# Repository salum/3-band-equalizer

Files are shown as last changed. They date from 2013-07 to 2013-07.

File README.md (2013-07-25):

# Equalizador de 3 bandas

Os Equalisadores de onda, consistem em controlar as frequências de um determinado sinal a fim de modificar a amplitude de uma certa frequência.

No caso de equalisadores de audio mais convencionais, utilizamos uma divisão simplificada das freqências, sendo elas denominadas baixas, médias e altas frequências, que regulam o grave (bass), medio(middle) e agudo(treble) respectivamente.

Para fim deste projeto, podemos considerar a seguinte sequência de blocos:

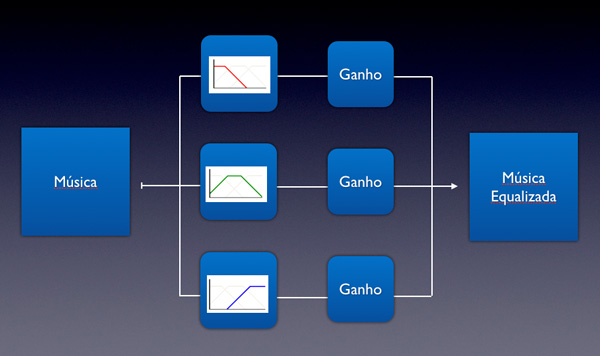
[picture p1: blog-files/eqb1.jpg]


Agora a pergunta seria: Qual tipo de filtro devemos utilizar?

Para responder esta pergunta, vamos olhar a tabela de filtros a segui, olhando qual filtro possui a característica que queremos, que é um filtro que possua uma linearidade maior em uma certa faixa de frequências.

Ao observarmos, o filtro que melhor se adapta é o Butterworth, que possui uma qualidade 0.707 e proporciona uma amplitude homogênia.

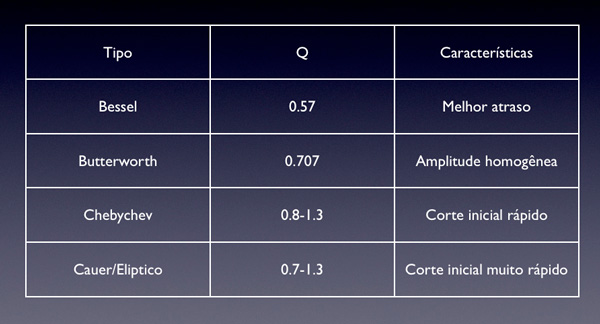
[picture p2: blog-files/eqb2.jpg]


Agora que já sabemos qual o melhor tipo, precisamos avaliar qual deverá ser a ordem deste filtro pois será ela que determinará o quão precido o filtro será, ou seja, após a frequência de corte, ele diminuirá n*20 dB por década. Para isso iremos utilizar a Equação 1, onde n é a ordem do filtro.

A partir da equação e das informações supracitadas, chegamos em um filtro Butterworth de segunda ordem, que nos proporcionará um ganho uniforme no passa faixa, além de uma queda relativamente brusca (40 dB por década) nas frequências de corte.l



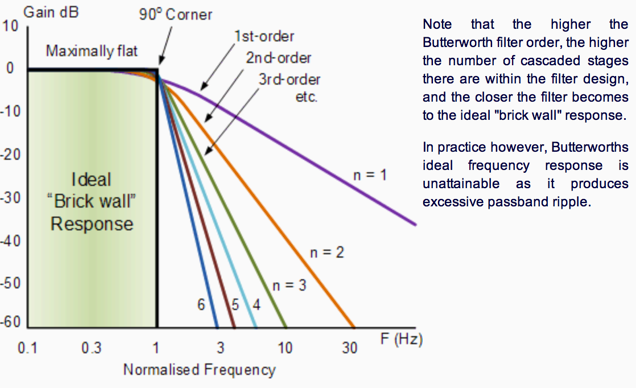
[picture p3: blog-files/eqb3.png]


Para determinarmos as frequências de corte, efetuamos pesquisas em livros, sites da internet e catálogos de equipamentos, onde verificamos que as frequências de corte são 300Hz e 3KHz.

A partir destes valores, e da equação padrão para determinação de frequências de corte, e fixando o valor da capacitância em 10uF, que proporciona uma constante de tempo baixa, chegamos nos valores de 53k e 5.3k para as frequências 300Hz e 3Khz respectivamente.

É importante notar que todo filtro Butterworth efetua uma defasagem de fase da ordem 90º, e que, no caso do Passabanda , que é formado por uma sequência de dois filtros, ocorre uma defasagem de 180º e que precisamos defasar este de -90º. Para isso adicionamos um "defasador" antes do passabanda.

A partir dos dados que possuímos, projetamos, simulamos, montamos e testamos os filtros necessários, utilizando a seguinte lista de componentes:

Protoboard
Ampop (TL074)
Capacitores de 10 uF
Resistores de 53K, 5.3K e 6.8K
Potenciômetros de 100K

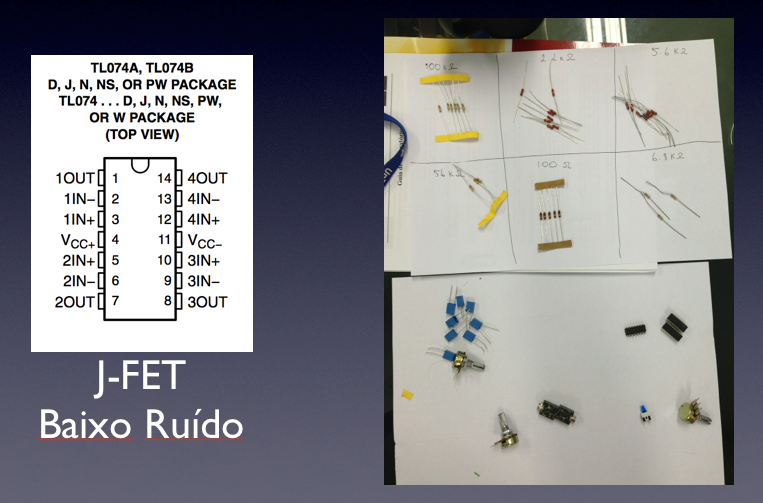
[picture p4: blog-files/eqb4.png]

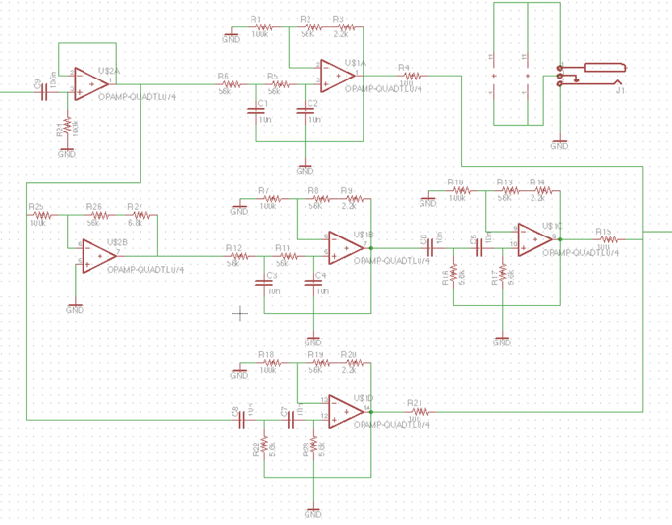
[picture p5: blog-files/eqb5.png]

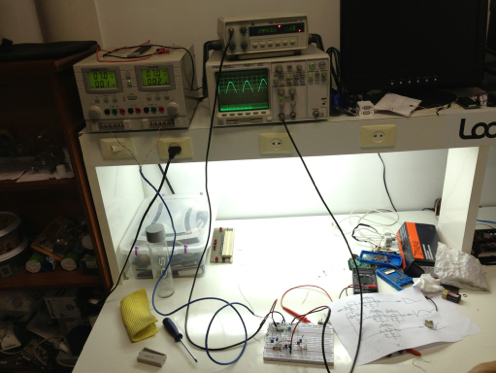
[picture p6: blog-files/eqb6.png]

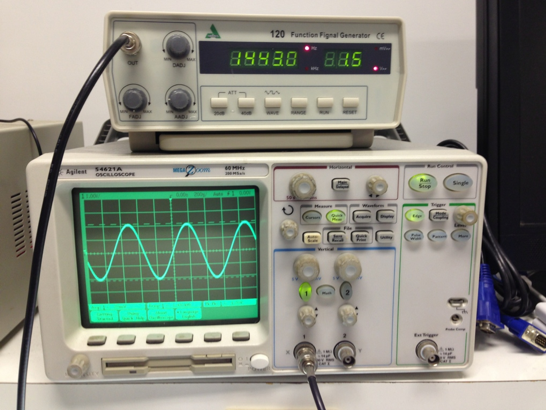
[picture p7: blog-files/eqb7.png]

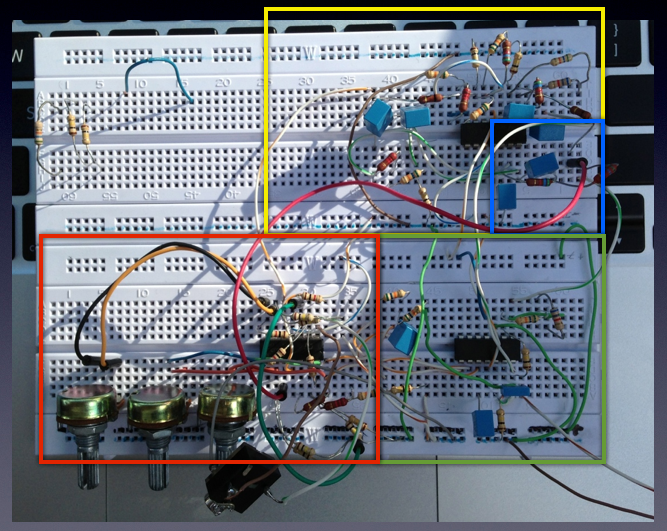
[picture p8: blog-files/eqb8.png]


Ao efetuarmos testes, notamos uma relação Sinal Ruido muito baixa, visto que estávamos efetuando uma amplificação no final de cada filtro.

Para uma segunda versão do atual projeto, iremos efetuar as seguintes tarefas.

- Avaliar técnicas de redução de ruídos
- Projetar divisor de tensão para utilizar somente uma fonte DC
- Estudar controle remoto do dispositivo
- Finalizar projeto PCB.

Bibliografia

- Integrated Electronics by Millman & Halkias

McGraw-Hill.

- Microelectronic Circuits 6th edition

[Download da apresentação 1](https://github.com/salum/3-band-equalizer/blob/master/presentations/1st%20presentation.pdf)

# Segunda versão
## implementação em PCB

Na segunda versão do Equalizador de 3 bandas, modificamos o projeto para obtermos uma redução de de ruídos, além de implementarmos ele em PCB, tornando o projeto mais robusto e mais organizado.

A fim de reduzirmos o ruído existente, decidimos por atuar no limite de saturação dos ampops, ou seja, adicionamos um amplificador de aproximadamente 8x na entrada do circuito.



Com esta modificação, foi necessário alterar também o modo com que os ampops de saída de cada faixa de equalização atuam, fazendo com que estes atuassem como atenuadores de sinal e não como amplificadores, como ocorrido na 1ª versão do projeto.

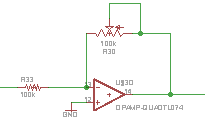
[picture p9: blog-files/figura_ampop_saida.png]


Após esta modificação do projeto, teremos o circuito a seguir, o qual deverá ser transferido para uma PCB.

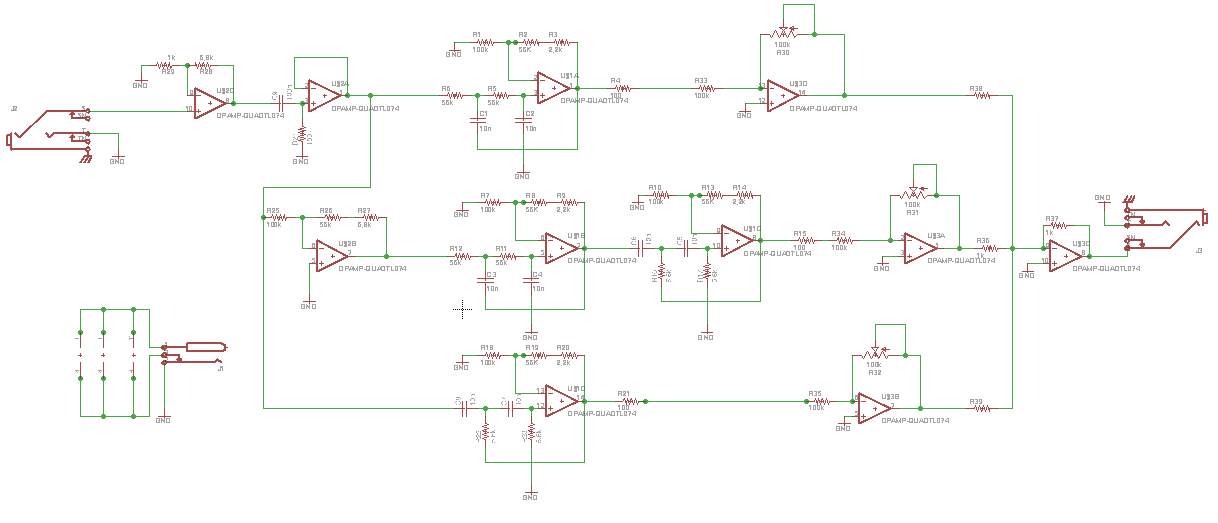
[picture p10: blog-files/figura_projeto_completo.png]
 

Para montarmos o projeto na PCB, utilizamos o software EAGLE - freeware e importando algumas bibliotecas externas do [Monowave](http://xdissent.github.io/monowave-eagle/libraries/index.html).

Após montarmos o circuito e posicionarmos as peças na placa, obtivemos o seguinte esquemático.

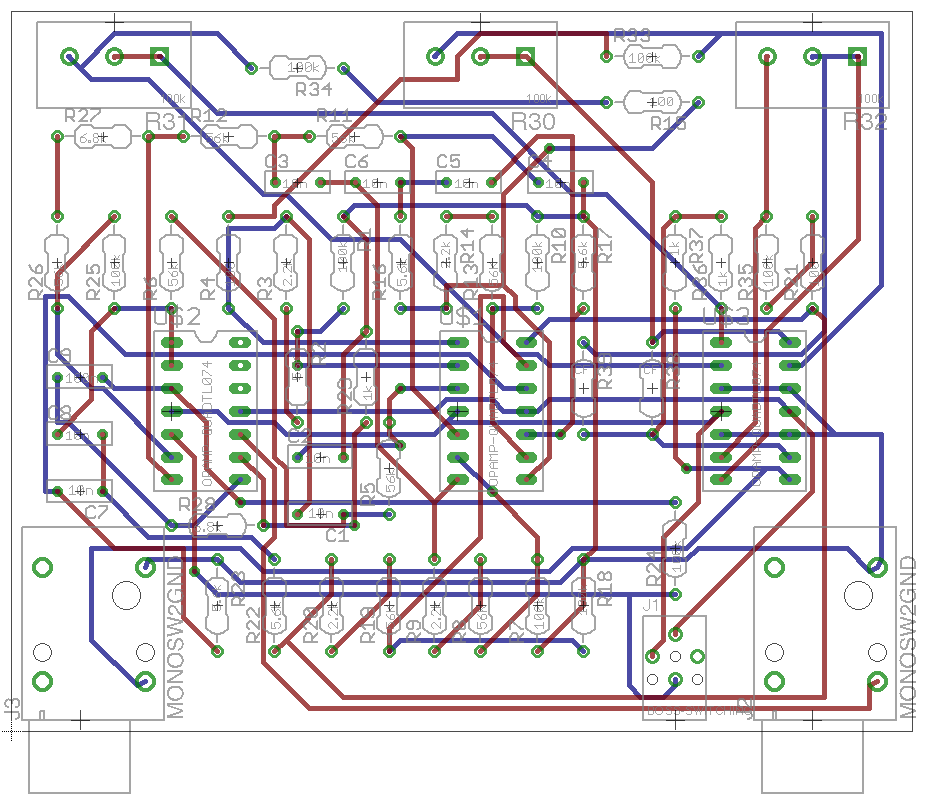
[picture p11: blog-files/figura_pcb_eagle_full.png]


Podemos notar que para fazermos tal placa, precisaríamos de impressão duplaface, além de trilhas de 10mm, o que dificulta a impressão e a montagem (sendo impossível fazer na DTL do SG11). Para isso, pegamos os padrões de impressão, assim como quais arquivos deveriam ser gerados para a confecção ser feita na Divisão Técnico Laboratorial do SG11 da Universidade de Brasília.

No final deste post tem um tutorial feito pelo Pedro Salum para auxiliar a impressão na DTL.

Ao observarmos o padrão necessário, tivemos que efetuar uma divisão do projeto da PCB em 3 partes, passa baixa, passa faixa e passa alta e depois interconectá-las por meio de fios.

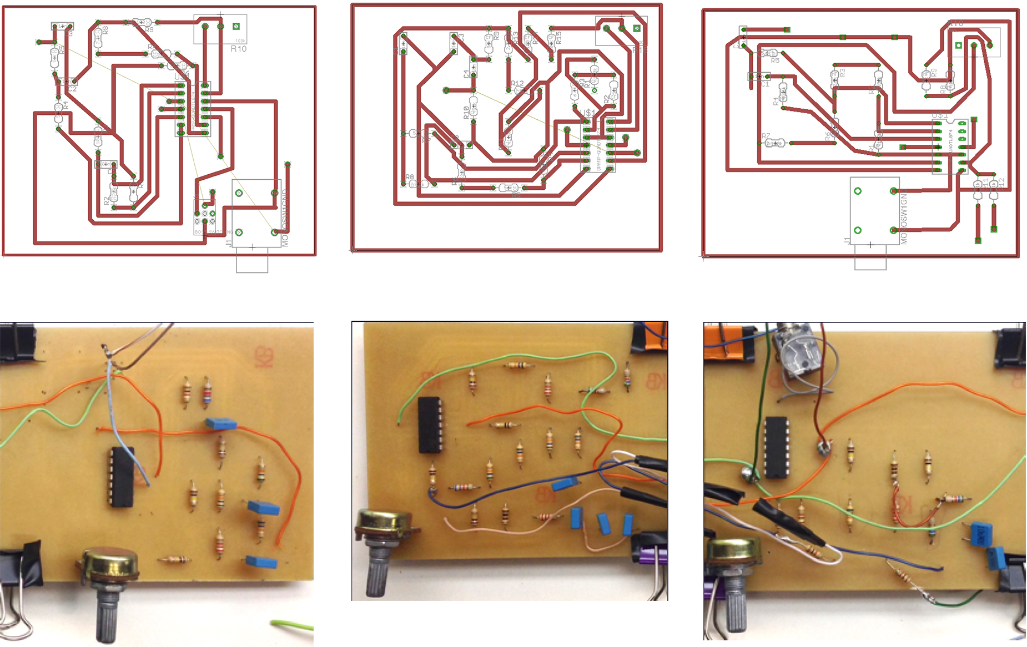
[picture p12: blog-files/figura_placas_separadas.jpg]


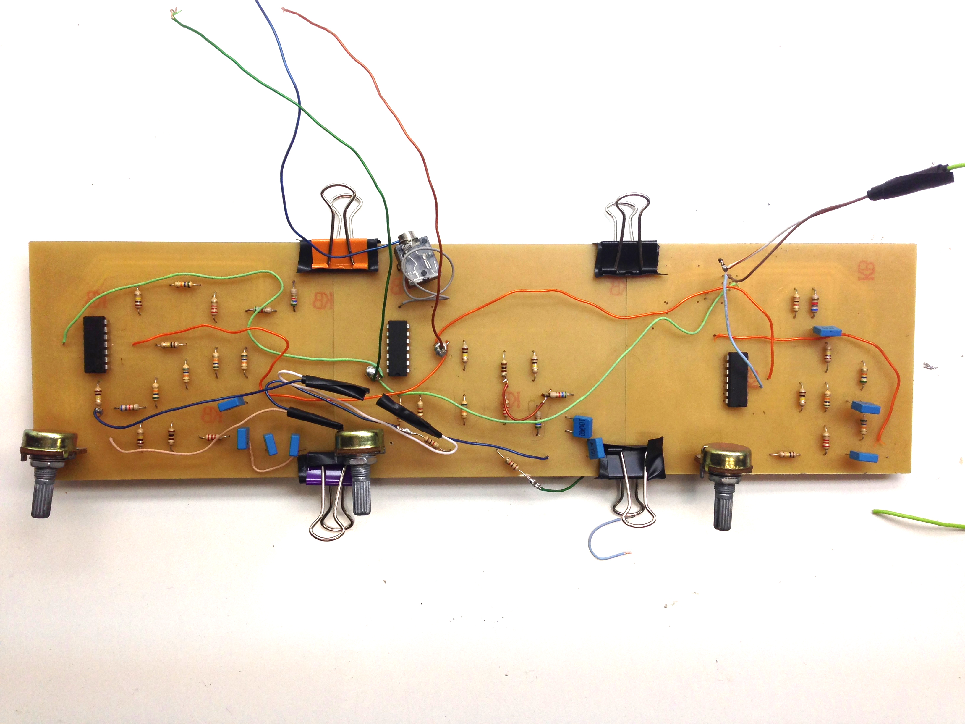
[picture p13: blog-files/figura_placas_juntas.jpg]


### Próximos passos

 - Empilhar placas a fim de reduzir espaço

 - criar uma case para o dispositivo

 - embutir um divisor de tensão a fim de utilizar uma fonte portátil.

[Download da Apresentação](https://github.com/salum/3-band-equalizer/raw/master/presentations/2nd%20presentation.pdf)

[Baixar Tutorial Eagle para Geber](#) (em breve)

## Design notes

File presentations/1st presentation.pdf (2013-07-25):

# Equalizador de 3 Bandas

3-band equalizer

# Equalizador de 3 Bandas

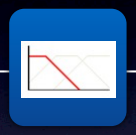
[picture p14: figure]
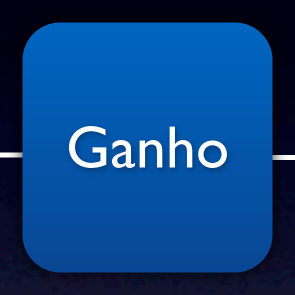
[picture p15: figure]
Ganho
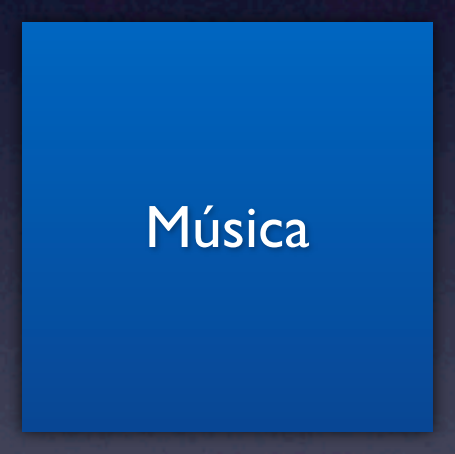
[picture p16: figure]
Música
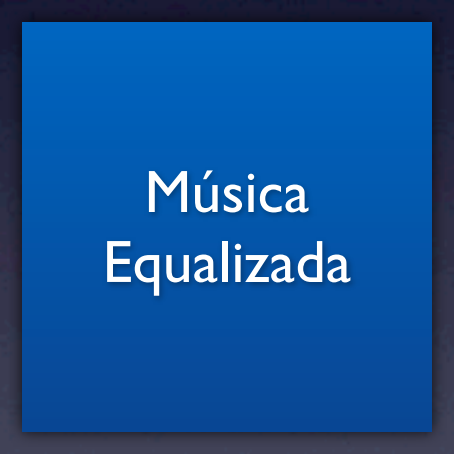
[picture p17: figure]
Música Equalizada
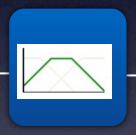
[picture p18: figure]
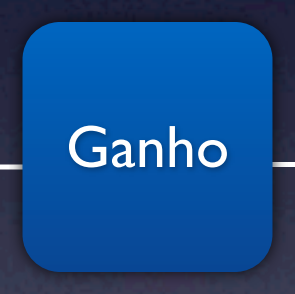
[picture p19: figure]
Ganho
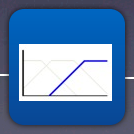
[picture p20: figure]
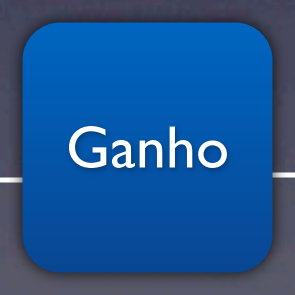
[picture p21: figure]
Ganho

# Equalizador de 3 Bandas

Tipo | Q | Características
Bessel | 0.57 | Melhor atraso
Butterworth | 0.707 | Amplitude homogênea
Chebychev | 0.8-1.3 | Corte inicial rápido
Cauer/Eliptico | 0.7-1.3 | Corte inicial muito rápido

# Equalizador de 3 Bandas

Filtros Butterworth

2ª Ordem

Q(fator de qualidade) = 0.707

Ganho uniforme em passa faixa

Queda brusca em frequências de corte

# Equalizador de 3 Bandas

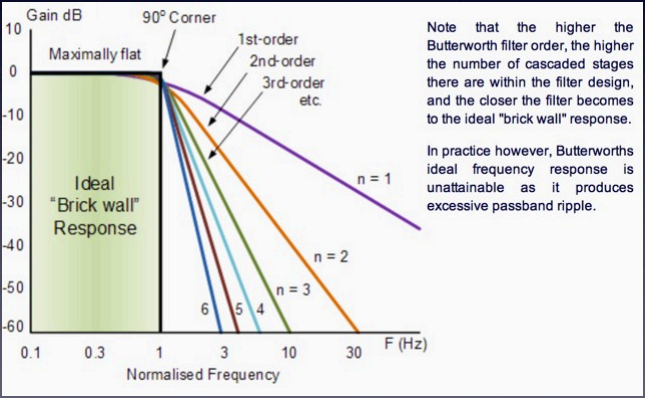
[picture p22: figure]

# Equalizador de 3 Bandas

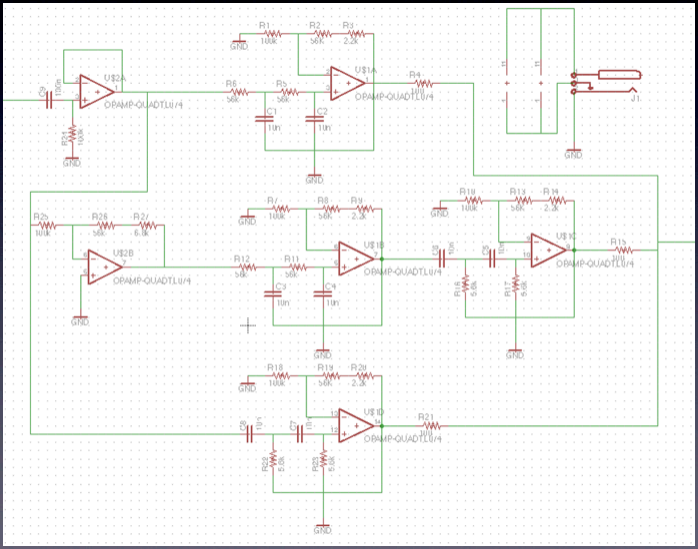
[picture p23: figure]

# Equalizador de 3 Bandas

f = 1 2.∏.R.C

C = 10nF
300Hz -- R = 53K
3KHz -- R = 5.3K

# Equalizador de 3 Bandas

Componentes Utilzados

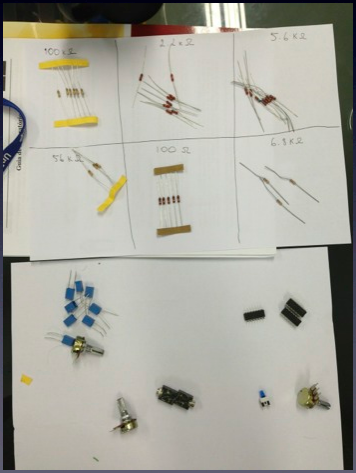
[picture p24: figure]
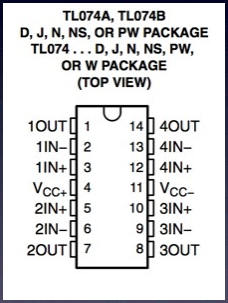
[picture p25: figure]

J-FET
Baixo Ruído

# Equalizador de 3 Bandas

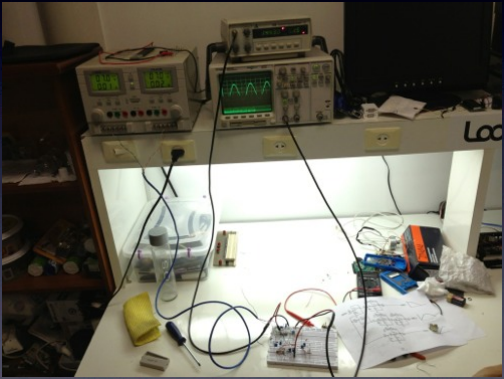
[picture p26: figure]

# Equalizador de 3 Bandas

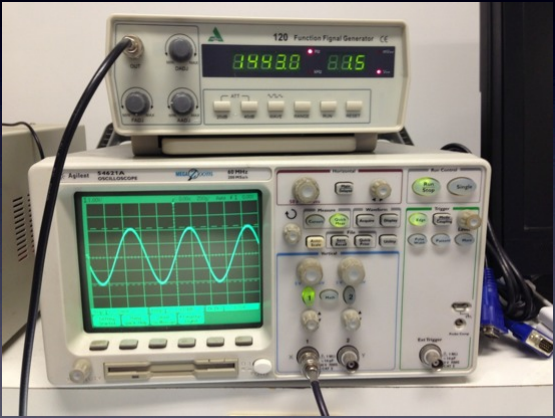
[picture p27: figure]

# Equalizador de 3 Bandas

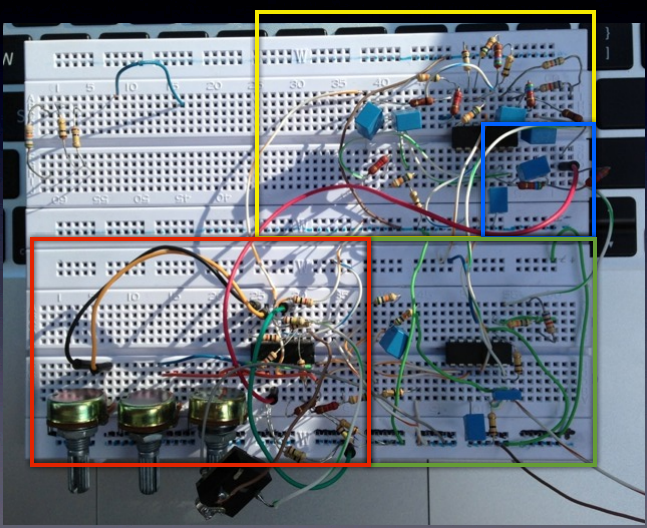
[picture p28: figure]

# Equalizador de 3 Bandas

Próximos Passos

- Avaliar técnicas de redução de ruídos;
- Projetar divisor de tensão para utilizar somente uma fonte DC;
- Estudar controle remoto do dispositivo;
- Finalizar projeto PCB.

# Equalizador de 3 Bandas

Bibliografia

- Integrated Electronics by Millman & Halkias McGraw-Hill.
- Microelectronic Circuits 6th edition

# Equalizador de 3 Bandas

Daniel Sandoval
Guilherme Alexsanders
Pedro Salum Franco

# Equalizador de 3 Bandas

## Dúvidas?

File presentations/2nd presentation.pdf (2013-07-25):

# Equalizador de 3 Bandas

3-band equalizer

# Equalizador de 3 Bandas

Ganho
Música
Música Equalizada
Ganho

# Equalizador de 3 Bandas

# Equalizador de 3 Bandas

Filtros Butterworth

# Equalizador de 3 Bandas

Filtros Butterworth

2ª Ordem

# Equalizador de 3 Bandas

Filtros Butterworth

2ª Ordem
Ganho uniforme em passa faixa

# Equalizador de 3 Bandas

Filtros Butterworth

2ª Ordem
Ganho uniforme em passa faixa

Queda brusca em frequências de corte

# Equalizador de 3 Bandas

f = 1 2.∏.R.C

C = 10nF
300Hz -- R = 53K
3KHz -- R = 5.3K

# Equalizador de 3 Bandas

Componentes Utilzados


J-FET
Baixo Ruído

# Equalizador de 3 Bandas

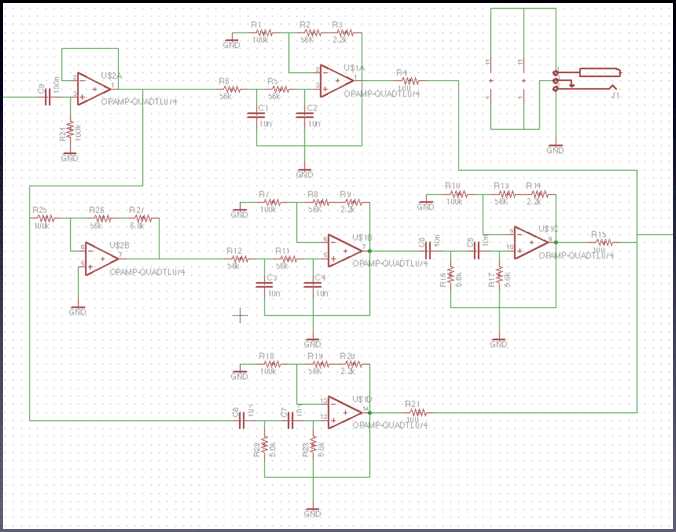
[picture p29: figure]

# Equalizador de 3 Bandas

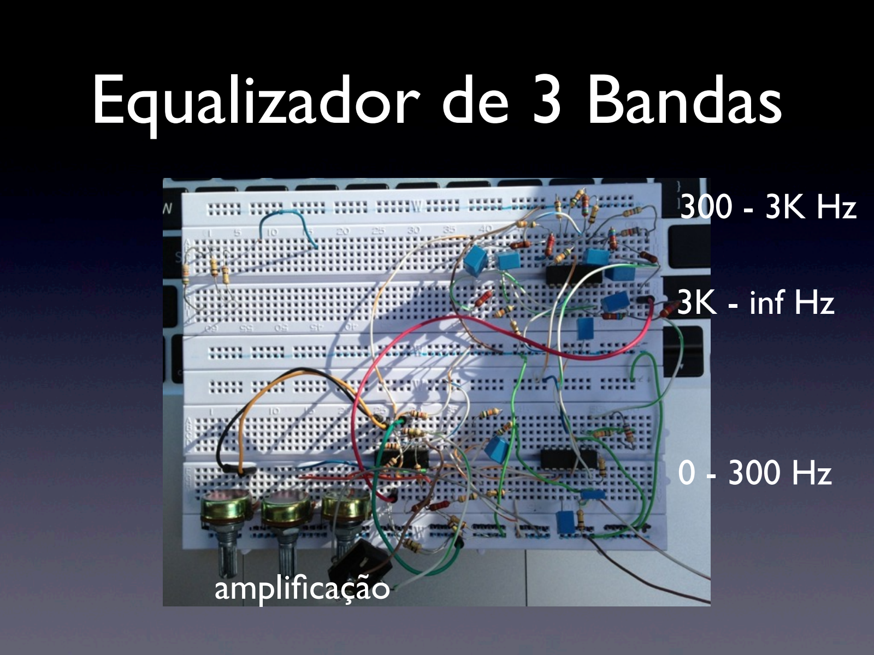
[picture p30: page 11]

amplificação

300 - 3K Hz

3K - inf Hz

0 - 300 Hz

# Equalizador de 3 Bandas

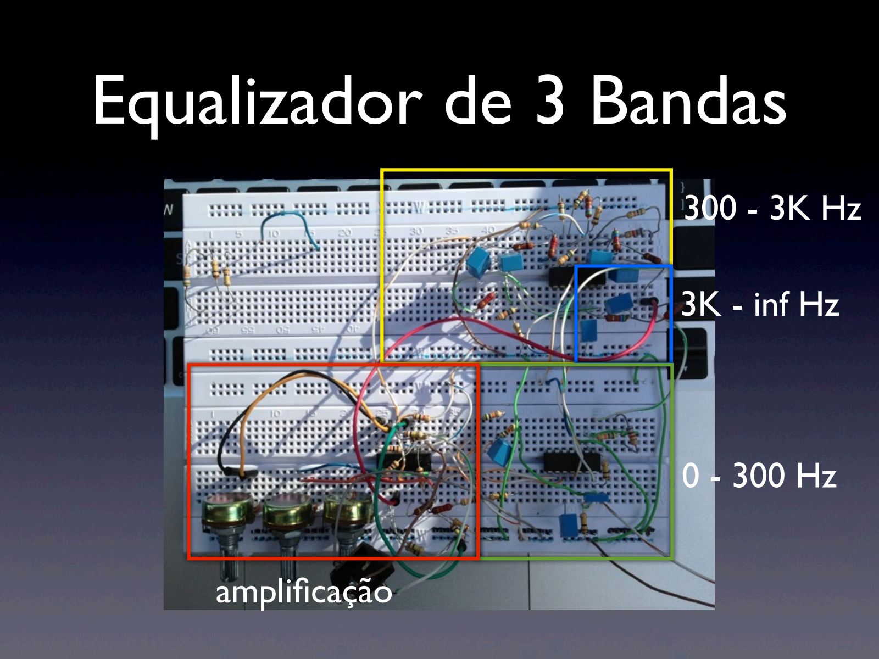
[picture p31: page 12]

amplificação

300 - 3K Hz

3K - inf Hz

0 - 300 Hz

# Equalizador de 3 Bandas

Problemas

- Ruido Aparente;
- Fisicamente Instável
- Necessita de fonte simétrica de 7V;

# Equalizador de 3 Bandas

# Equalizador de 3 Bandas

# Modelo 2.0

# Equalizador de 3 Bandas

Modelo 2.0

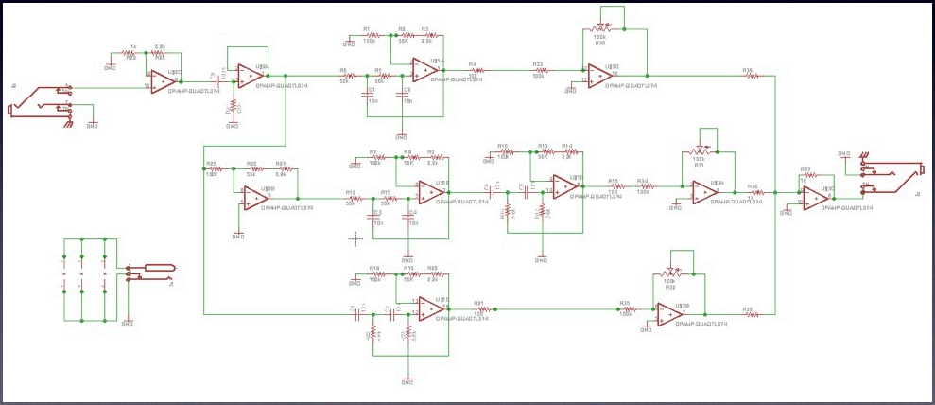
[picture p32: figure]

# Equalizador de 3 Bandas

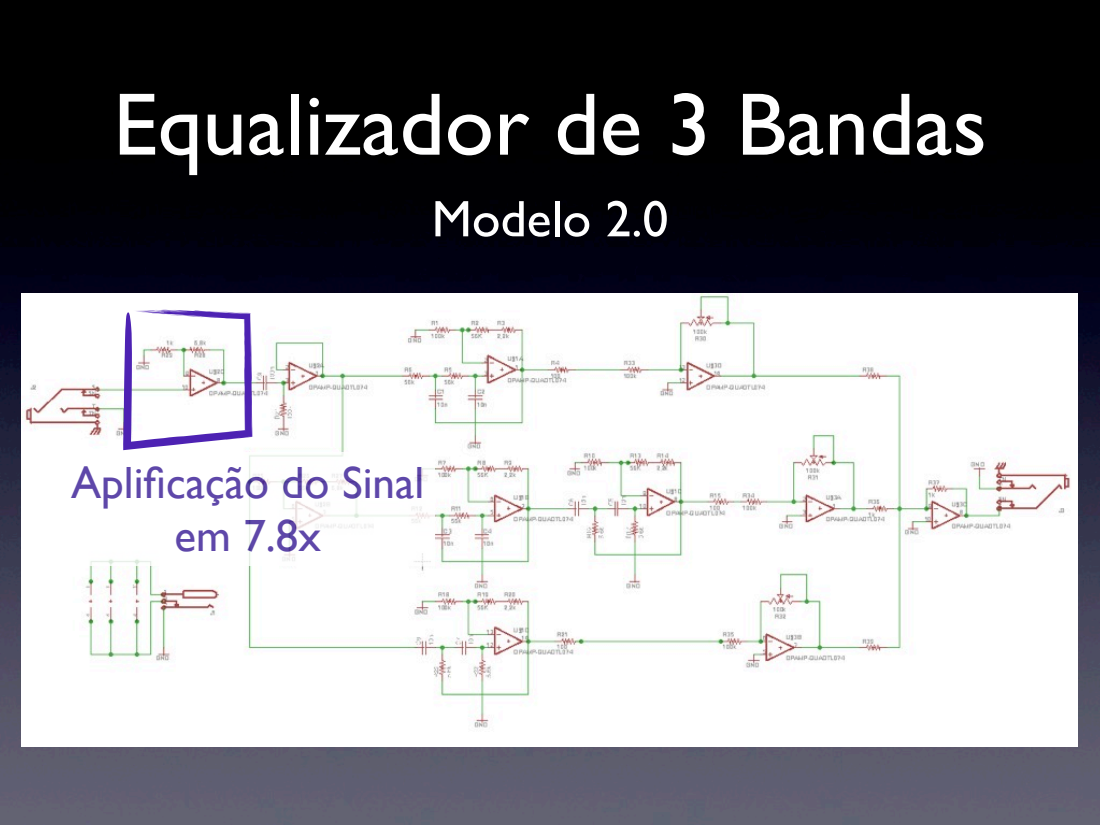
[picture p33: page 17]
Modelo 2.0

Aplificação do Sinal

# Equalizador de 3 Bandas

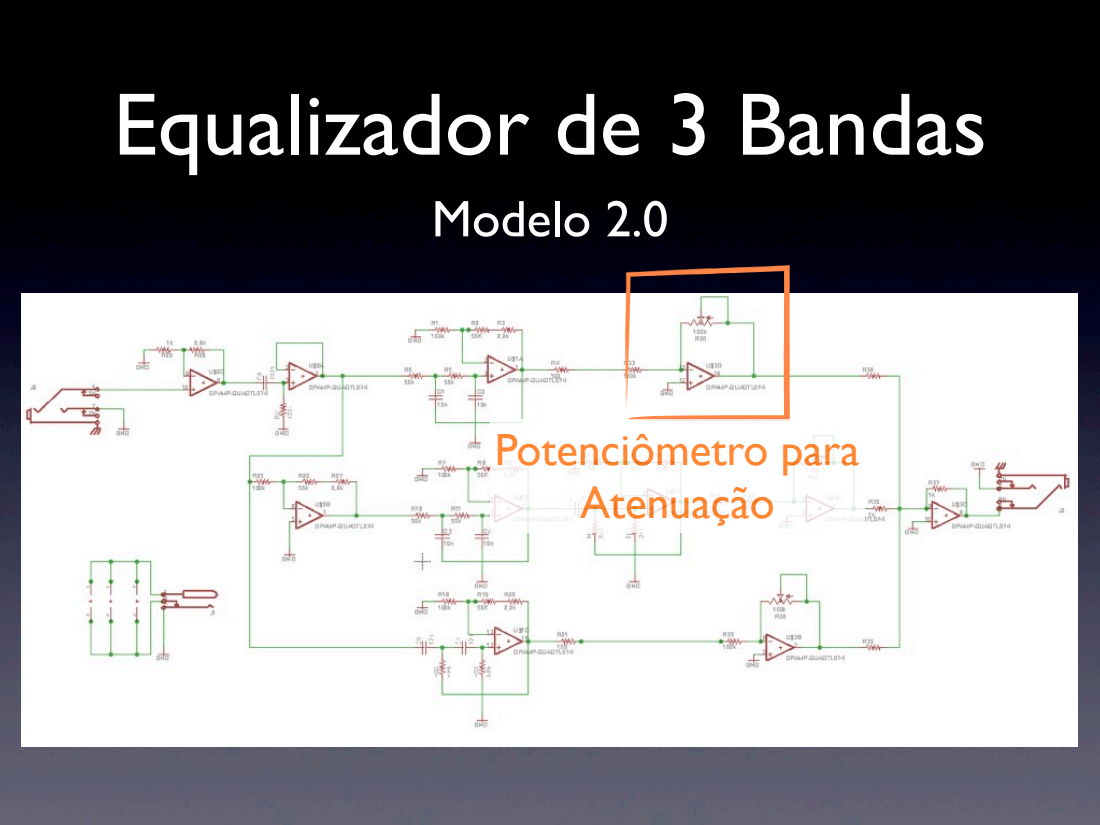
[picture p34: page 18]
Modelo 2.0; Potenciômetro para Atenuação

# Equalizador de 3 Bandas

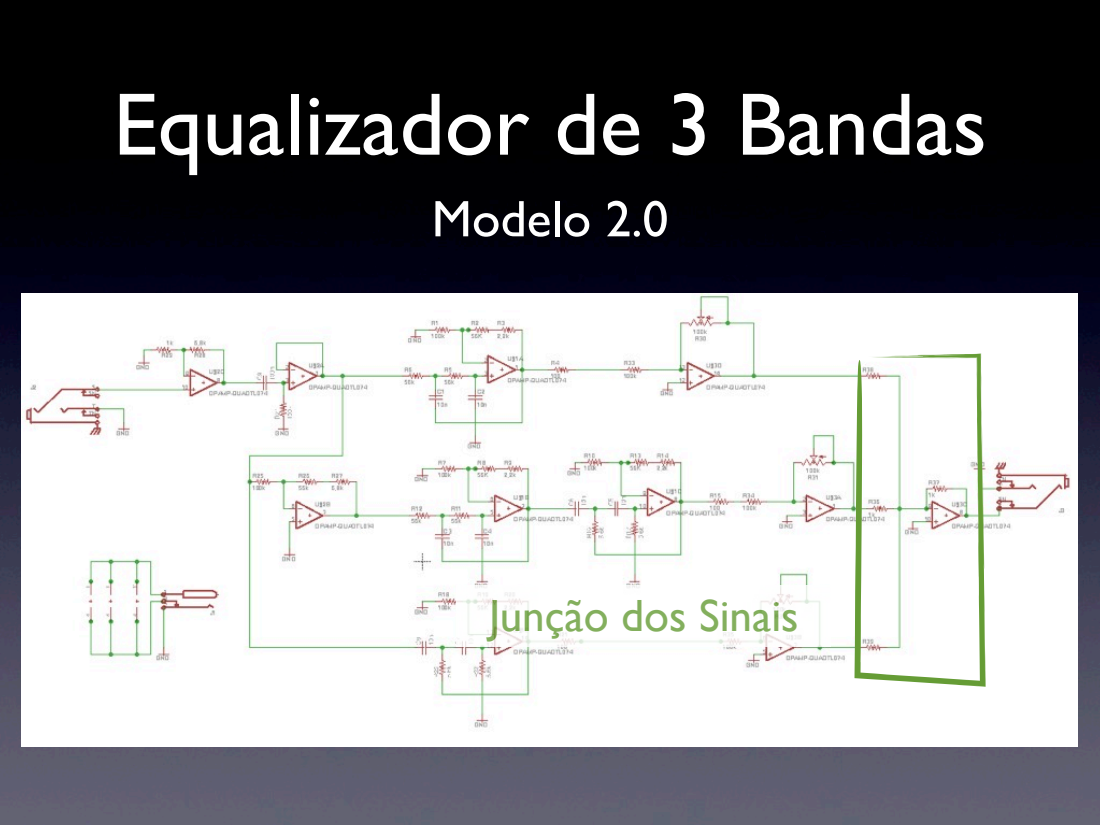
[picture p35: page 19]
Modelo 2.0

Junção dos Sinais

# Equalizador de 3 Bandas

Modelo 2.0

8 cm

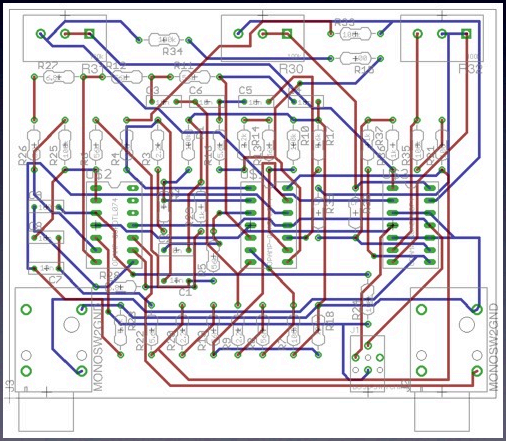
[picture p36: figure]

10 cm

# Equalizador de 3 Bandas

Modelo 2.0

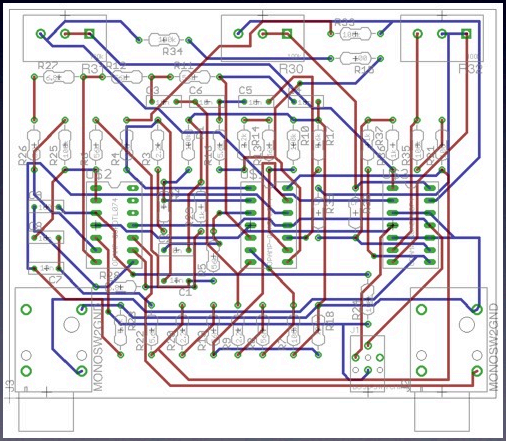
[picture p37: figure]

Trilhas pequenas

Dupla Face

Solda complicada

# Equalizador de 3 Bandas

Modelo 2.0

Dupla Face X Solda complicada

Trilhas pequenas

# Equalizador de 3 Bandas

Modelo 2.0


# Equalizador de 3 Bandas

Modelo 2.0

# Equalizador de 3 Bandas

Modelo 2.0


# Equalizador de 3 Bandas


Modelo 2.0

# Equalizador de 3 Bandas


Modelo 2.0

# Equalizador de 3 Bandas

Modelo 2.0


# Equalizador de 3 Bandas

Modelo 2.0
\m/

# Equalizador de 3 Bandas

Próximos Passos

- Empilhar as placas a fim de reduzir espaço
- Criar uma case para o dispositivo
- Embutir um divisor de tensão

# Equalizador de 3 Bandas

Bibliografia

- Integrated Electronics by Millman & Halkias McGraw-Hill.
- Microelectronic Circuits 6th edition

# Equalizador de 3 Bandas

Daniel Sandoval
Guilherme Aleksanders
Pedro Salum Franco

# Equalizador de 3 Bandas

## Dúvidas?

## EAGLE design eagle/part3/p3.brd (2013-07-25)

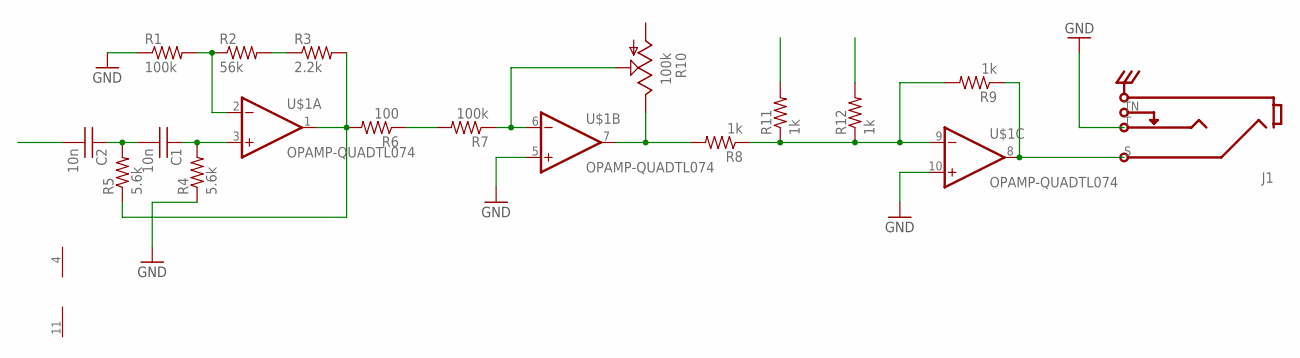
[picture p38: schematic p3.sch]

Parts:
C1, C2: 10n; BOX-2.5MM-7.2MM
J1: MONOSW1GND; NEUTRIK-NRJ4HM-1
R1, R7: 100k; 0.25W-0.4IN-METALFILM
R2: 56k; 0.25W-0.4IN-METALFILM
R3: 2.2k; 0.25W-0.4IN-METALFILM
R4, R5: 5.6k; 0.25W-0.4IN-METALFILM
R6: 100; 0.25W-0.4IN-METALFILM
R8, R9: 1k; 0.25W-0.4IN-METALFILM
R10: 100k; POT-SIDE-16MM-BITECH-P160KN
R11, R12: 1k; 0.25W-0.4IN
U$1: OPAMP-QUADTL074; DIP14

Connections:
0: J1.T, R1.1, R4.1, U$1.5 (IN+), U$1.10 (IN+)
unnamed: R1.2, R2.1, U$1.2 (IN-)
unnamed: R2.2, R3.1
unnamed: R3.2, R5.1, R6.2, U$1.1 (OUT)
unnamed: R6.1, R7.2
unnamed: R7.1, R10.P$2 (2), U$1.6 (IN-)
unnamed: R8.2, R10.P$3 (3), U$1.7 (OUT)
unnamed: R8.1, R9.2, R11.1, R12.1, U$1.9 (IN-)
unnamed: J1.S, R9.1, U$1.8 (OUT)
unnamed: C1.P$1 (1), R4.2, U$1.3 (IN+)
unnamed: C1.P$2 (2), C2.P$1 (1), R5.2
VCC: U$1.4 (VCC)
VEE: U$1.11 (VEE)

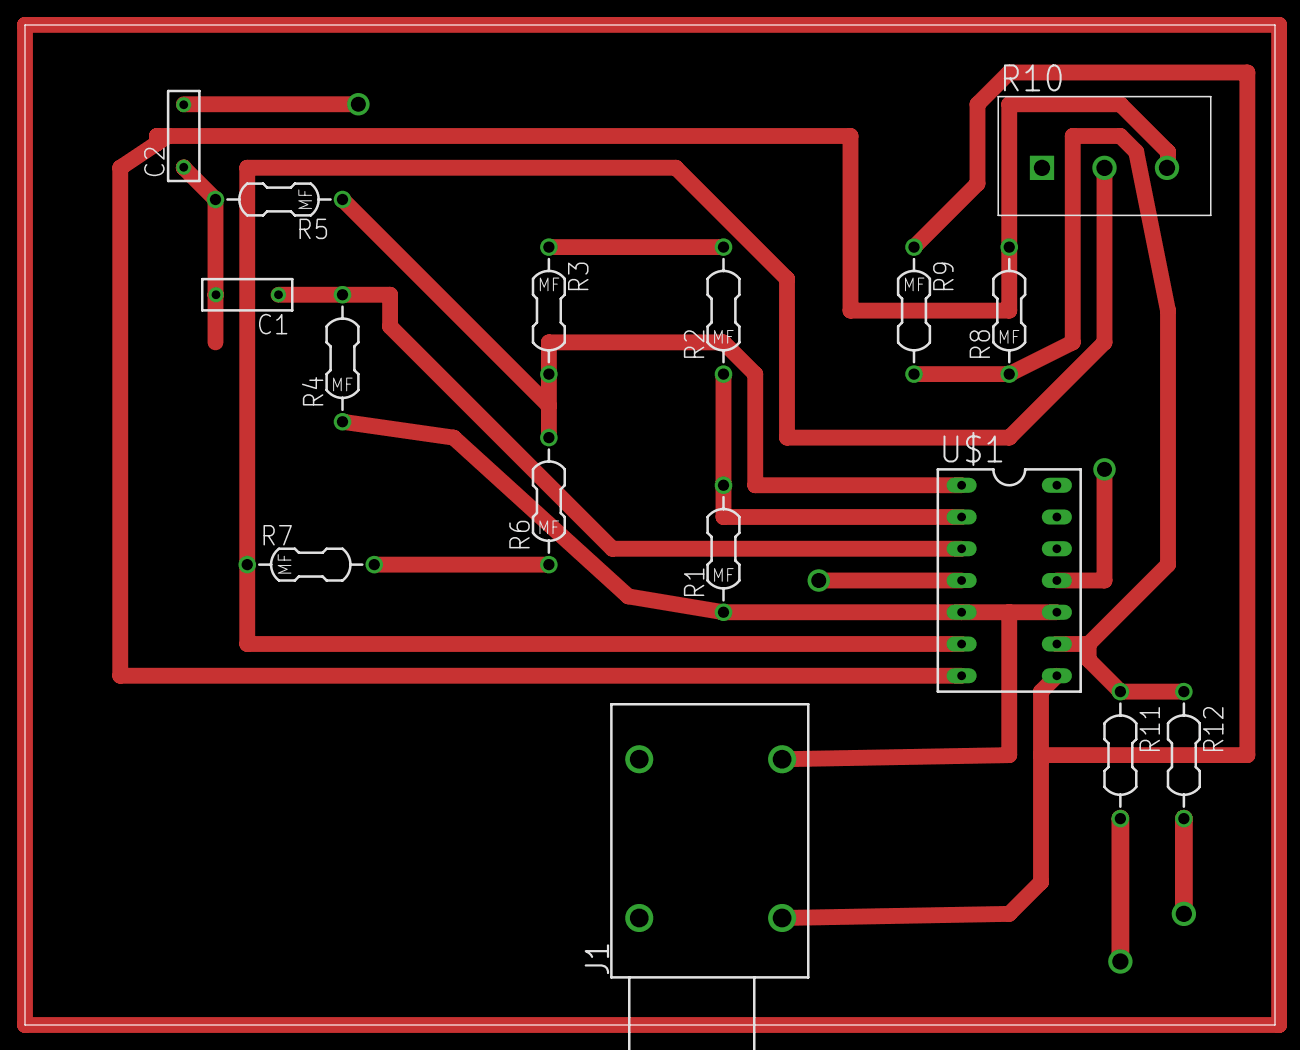
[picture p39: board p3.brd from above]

Board: 2 copper layers, 100.0 x 80.0 mm, 16 parts (0 on the bottom side), 11 nets.

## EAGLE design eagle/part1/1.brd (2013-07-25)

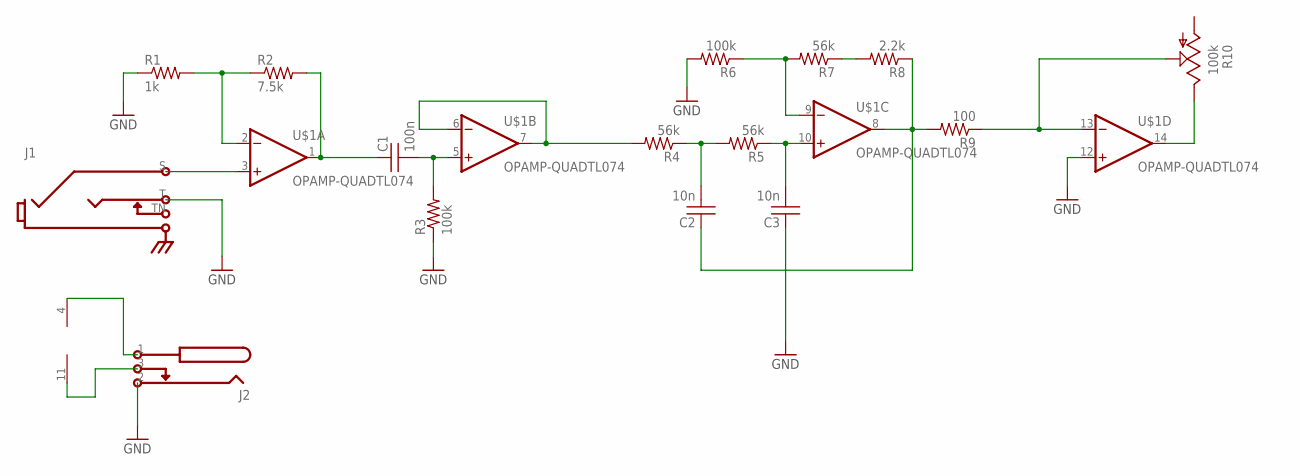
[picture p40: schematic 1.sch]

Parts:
C1: 100n; BOX-2.5MM-7.2MM
C2, C3: 10n; BOX-2.5MM-7.2MM
J1: MONOSW1GND; NEUTRIK-NRJ4HM-1
J2: BOSS-SWITCHING; KOBICONN-163-5010-E
R1: 1k; 0.25W-0.4IN-CARBONCOMP
R2: 7.5k; 0.25W-0.4IN-CARBONCOMP
R3, R6: 100k; 0.25W-0.4IN-CARBONCOMP
R4, R5, R7: 56k; 0.25W-0.4IN-CARBONCOMP
R8: 2.2k; 0.25W-0.4IN-CARBONCOMP
R9: 100; 0.25W-0.4IN-CARBONCOMP
R10: 100k; POT-SIDE-16MM-BITECH-P160KN
U$1: OPAMP-QUADTL074; DIP14

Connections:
0: C3.P$1 (1), J1.T, J2.2 (VCC), R1.1, R3.1, R6.2, U$1.12 (IN+)
unnamed: R1.2, R2.1, U$1.2 (IN-)
unnamed: C1.P$1 (1), R2.2, U$1.1 (OUT)
unnamed: C1.P$2 (2), R3.2, U$1.5 (IN+)
unnamed: R4.2, U$1.6 (IN-), U$1.7 (OUT)
unnamed: C2.P$2 (2), R4.1, R5.2
unnamed: C3.P$2 (2), R5.1, U$1.10 (IN+)
unnamed: R10.P$3 (3), U$1.14 (OUT)
unnamed: R6.1, R7.2, U$1.9 (IN-)
unnamed: R7.1, R8.2
unnamed: J1.S, U$1.3 (IN+)
unnamed: R9.1, R10.P$2 (2), U$1.13 (IN-)
unnamed: J2.1 (GND), U$1.4 (VCC)
unnamed: J2.3 (SW), U$1.11 (VEE)
unnamed: C2.P$1 (1), R8.1, R9.2, U$1.8 (OUT)

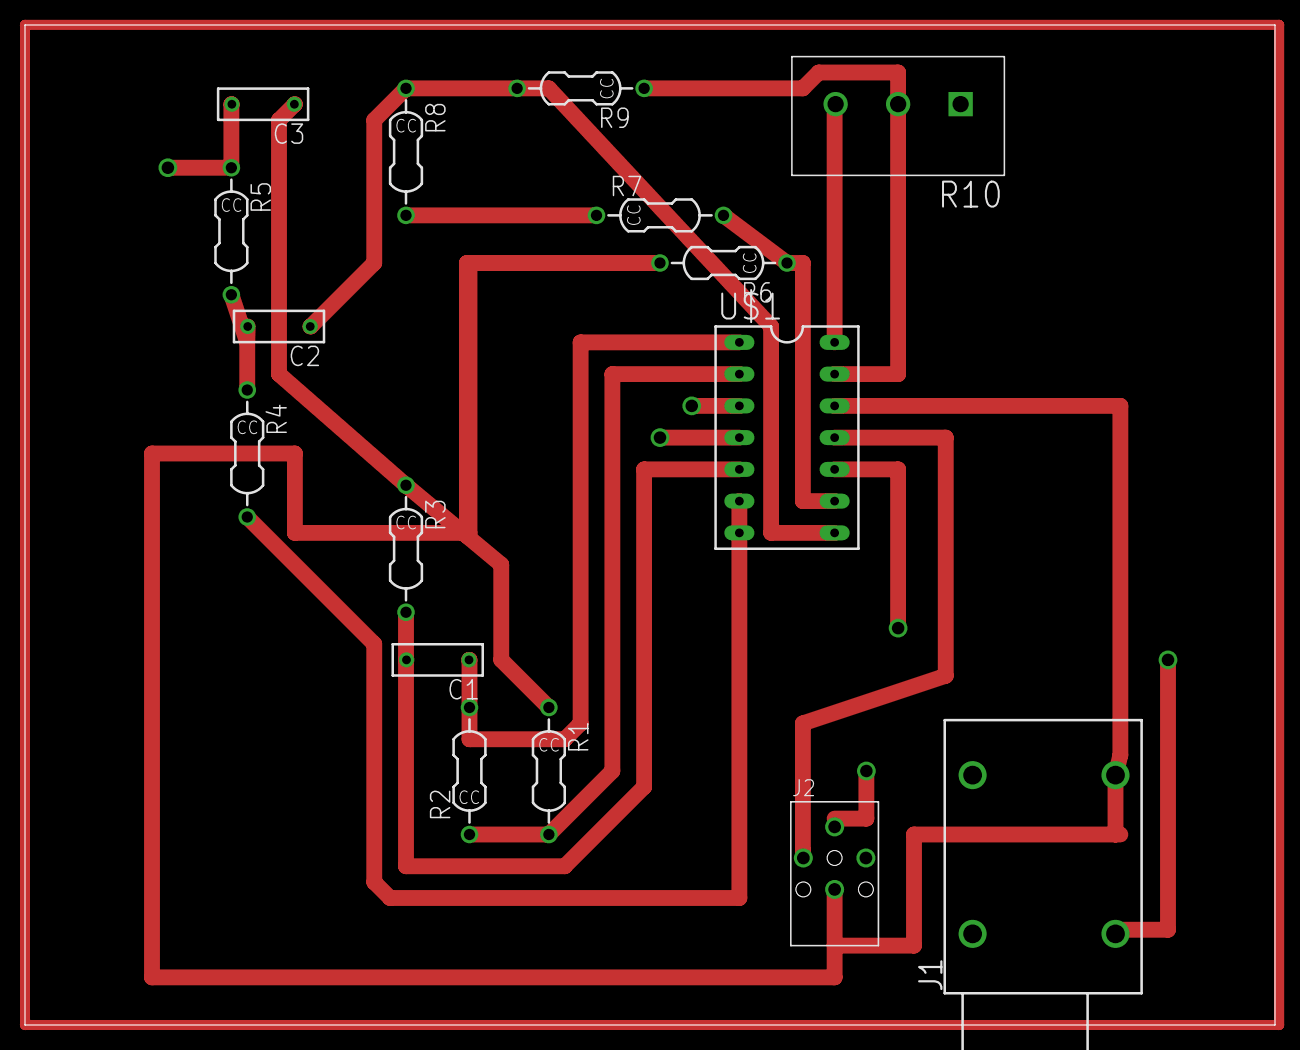
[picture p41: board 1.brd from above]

Board: 2 copper layers, 100.0 x 80.0 mm, 16 parts (0 on the bottom side), 15 nets.

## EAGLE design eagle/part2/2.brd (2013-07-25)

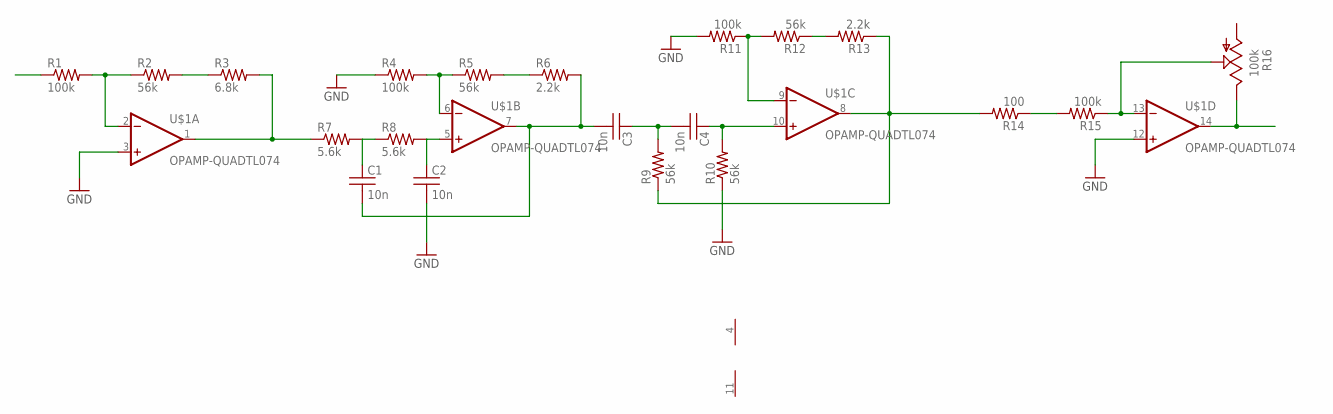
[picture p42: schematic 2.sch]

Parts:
C1, C2, C3, C4: 10n; BOX-2.5MM-7.2MM
R1, R4, R11, R15: 100k; 0.25W-0.4IN-CARBONFILM
R2, R5, R9, R10, R12: 56k; 0.25W-0.4IN-CARBONFILM
R3: 6.8k; 0.25W-0.4IN-CARBONFILM
R6, R13: 2.2k; 0.25W-0.4IN-CARBONFILM
R7, R8: 5.6k; 0.25W-0.4IN-CARBONFILM
R14: 100; 0.25W-0.4IN-CARBONFILM
R16: 100k; POT-SIDE-16MM-BITECH-P160KN
U$1: OPAMP-QUADTL074; DIP14

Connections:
0: C2.P$2 (2), R4.1, R10.1, R11.2, U$1.3 (IN+), U$1.12 (IN+)
unnamed: R1.2, R2.1, U$1.2 (IN-)
unnamed: R2.2, R3.1
unnamed: R3.2, R7.1, U$1.1 (OUT)
unnamed: C1.P$1 (1), R7.2, R8.1
unnamed: C2.P$1 (1), R8.2, U$1.5 (IN+)
unnamed: R4.2, R5.1, U$1.6 (IN-)
unnamed: R5.2, R6.1
unnamed: R16.P$3 (3), U$1.14 (OUT)
unnamed: C3.P$1 (1), C4.P$2 (2), R9.2
unnamed: R11.1, R12.2, U$1.9 (IN-)
unnamed: R12.1, R13.2
unnamed: C4.P$1 (1), R10.2, U$1.10 (IN+)
unnamed: R14.1, R15.2
unnamed: R15.1, R16.P$2 (2), U$1.13 (IN-)
unnamed: C1.P$2 (2), C3.P$2 (2), R6.2, U$1.7 (OUT)
unnamed: R9.1, R13.1, R14.2, U$1.8 (OUT)
VCC: U$1.4 (VCC)
VEE: U$1.11 (VEE)

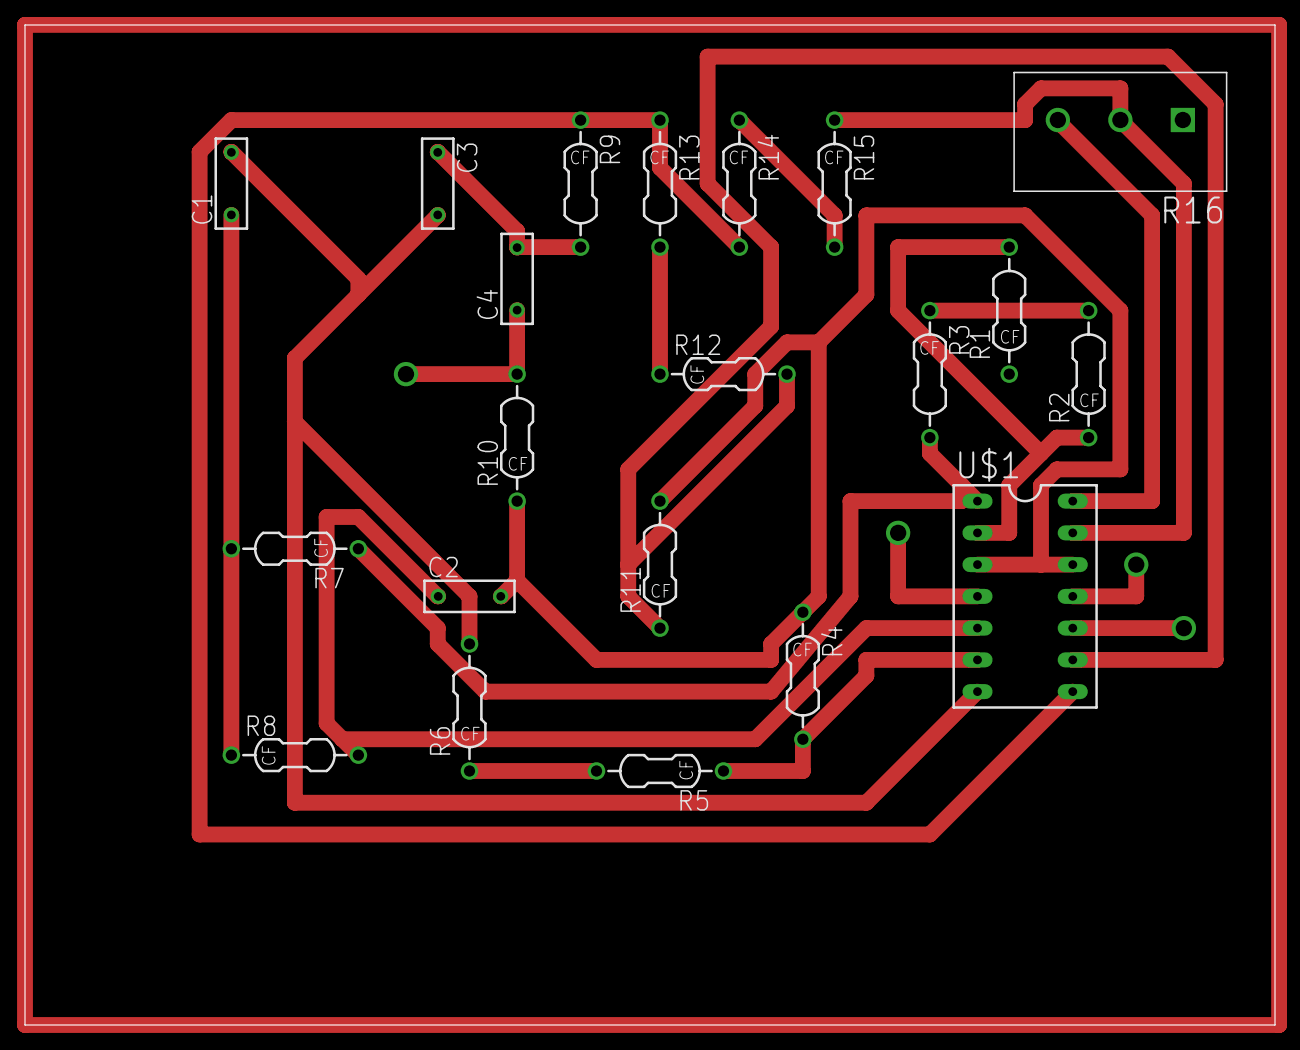
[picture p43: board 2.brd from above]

Board: 2 copper layers, 100.0 x 80.0 mm, 21 parts (0 on the bottom side), 17 nets.
